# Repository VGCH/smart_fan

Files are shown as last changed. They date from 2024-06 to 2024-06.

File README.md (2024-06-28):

## Проект домашней автоматизации вытяжной вентиляции 

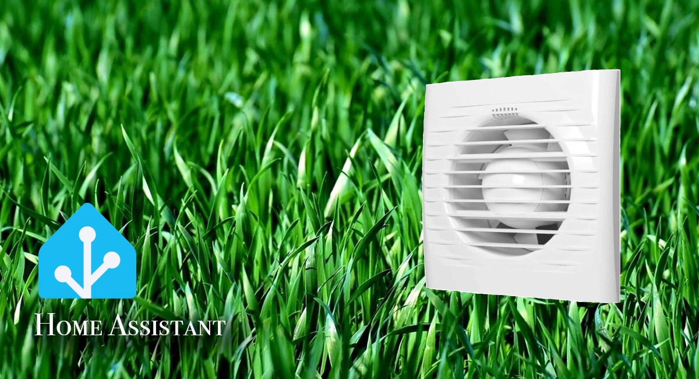
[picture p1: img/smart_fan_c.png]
Иллюстрация к проекту


Принципиальная схема системы управления
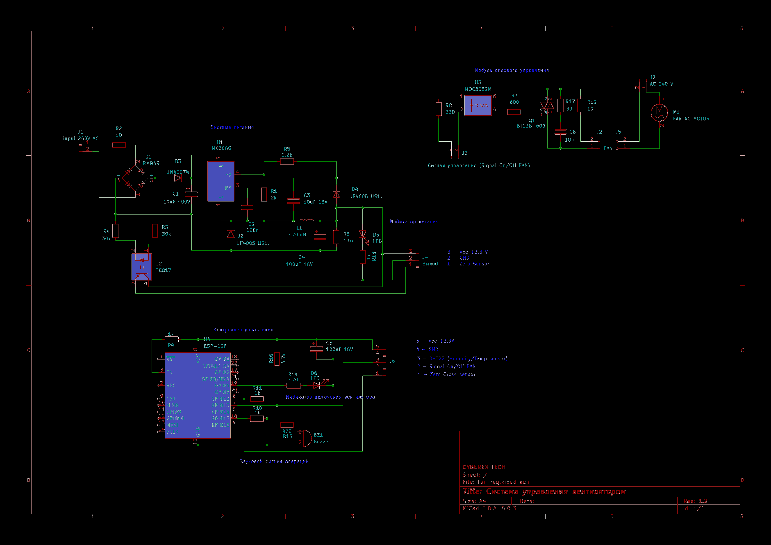
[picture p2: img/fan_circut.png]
Принципиальная схема


Полное описание в статье на Хабр

[Ссылка на статью ](https://habr.com/ru/articles/823752/)

Поддержать автора можно на Boosty

[Ссылка на Boosty](https://boosty.to/cyberex_tech)

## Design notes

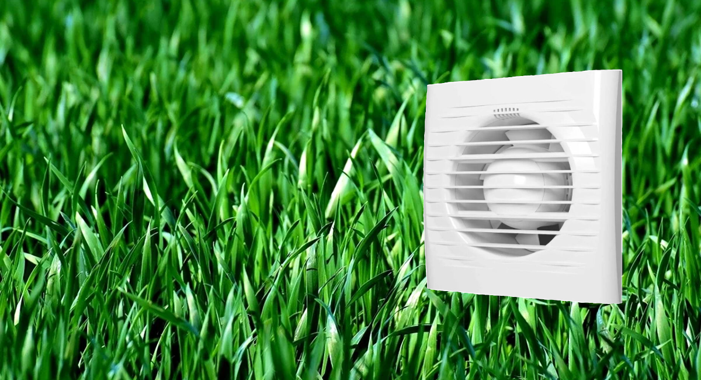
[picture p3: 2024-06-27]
img/smart_fan.png

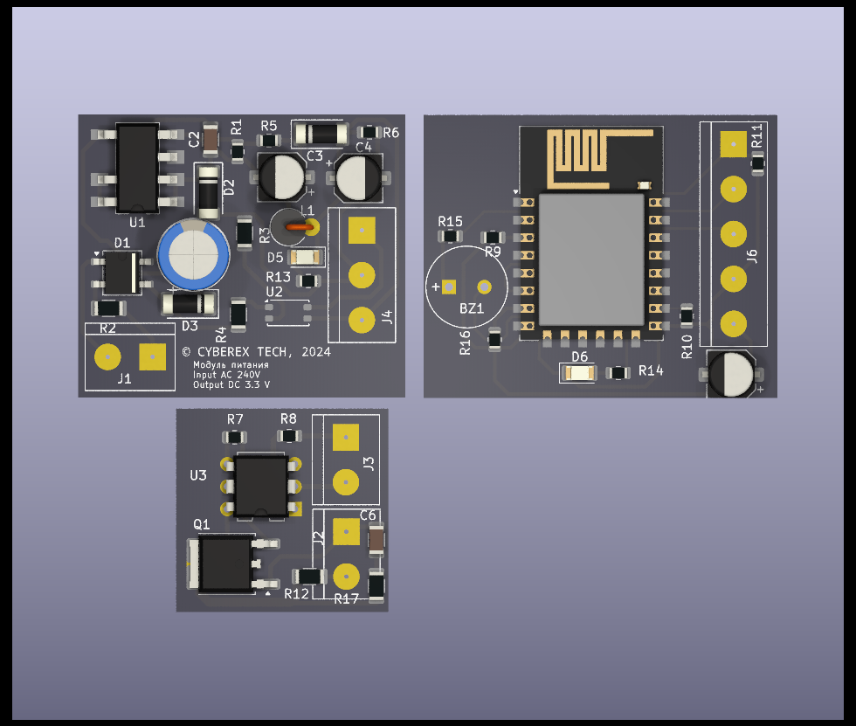
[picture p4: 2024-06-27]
fan_reg/fan_reg.png

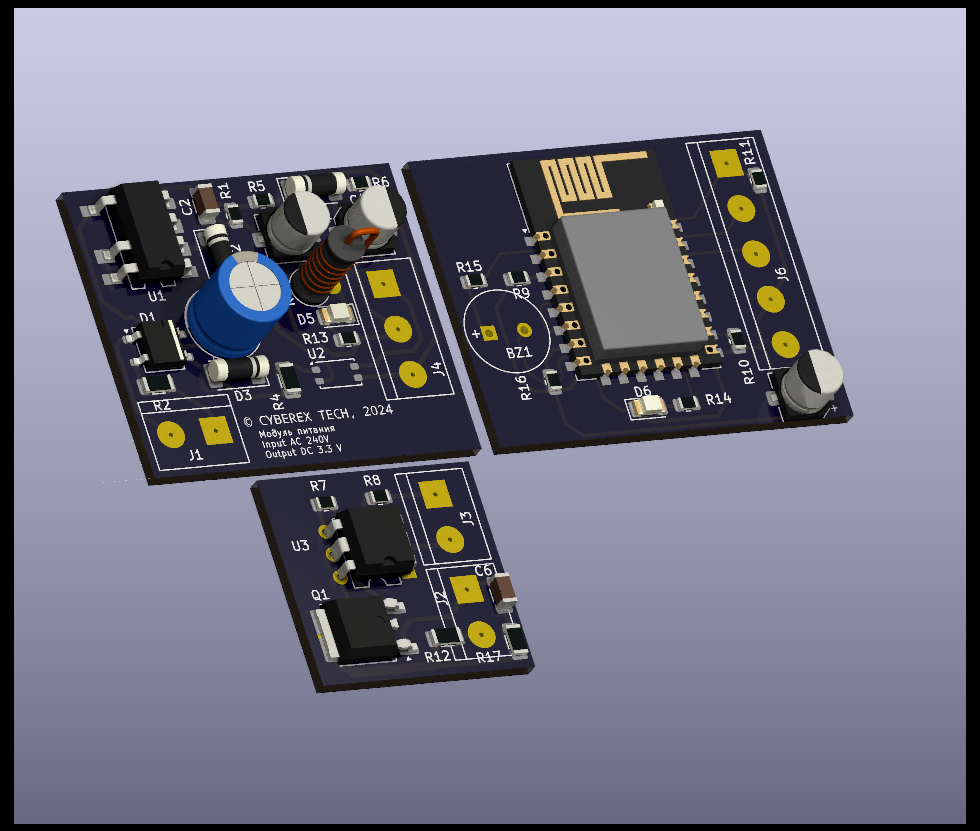
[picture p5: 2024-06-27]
fan_reg/fan_reg2.png

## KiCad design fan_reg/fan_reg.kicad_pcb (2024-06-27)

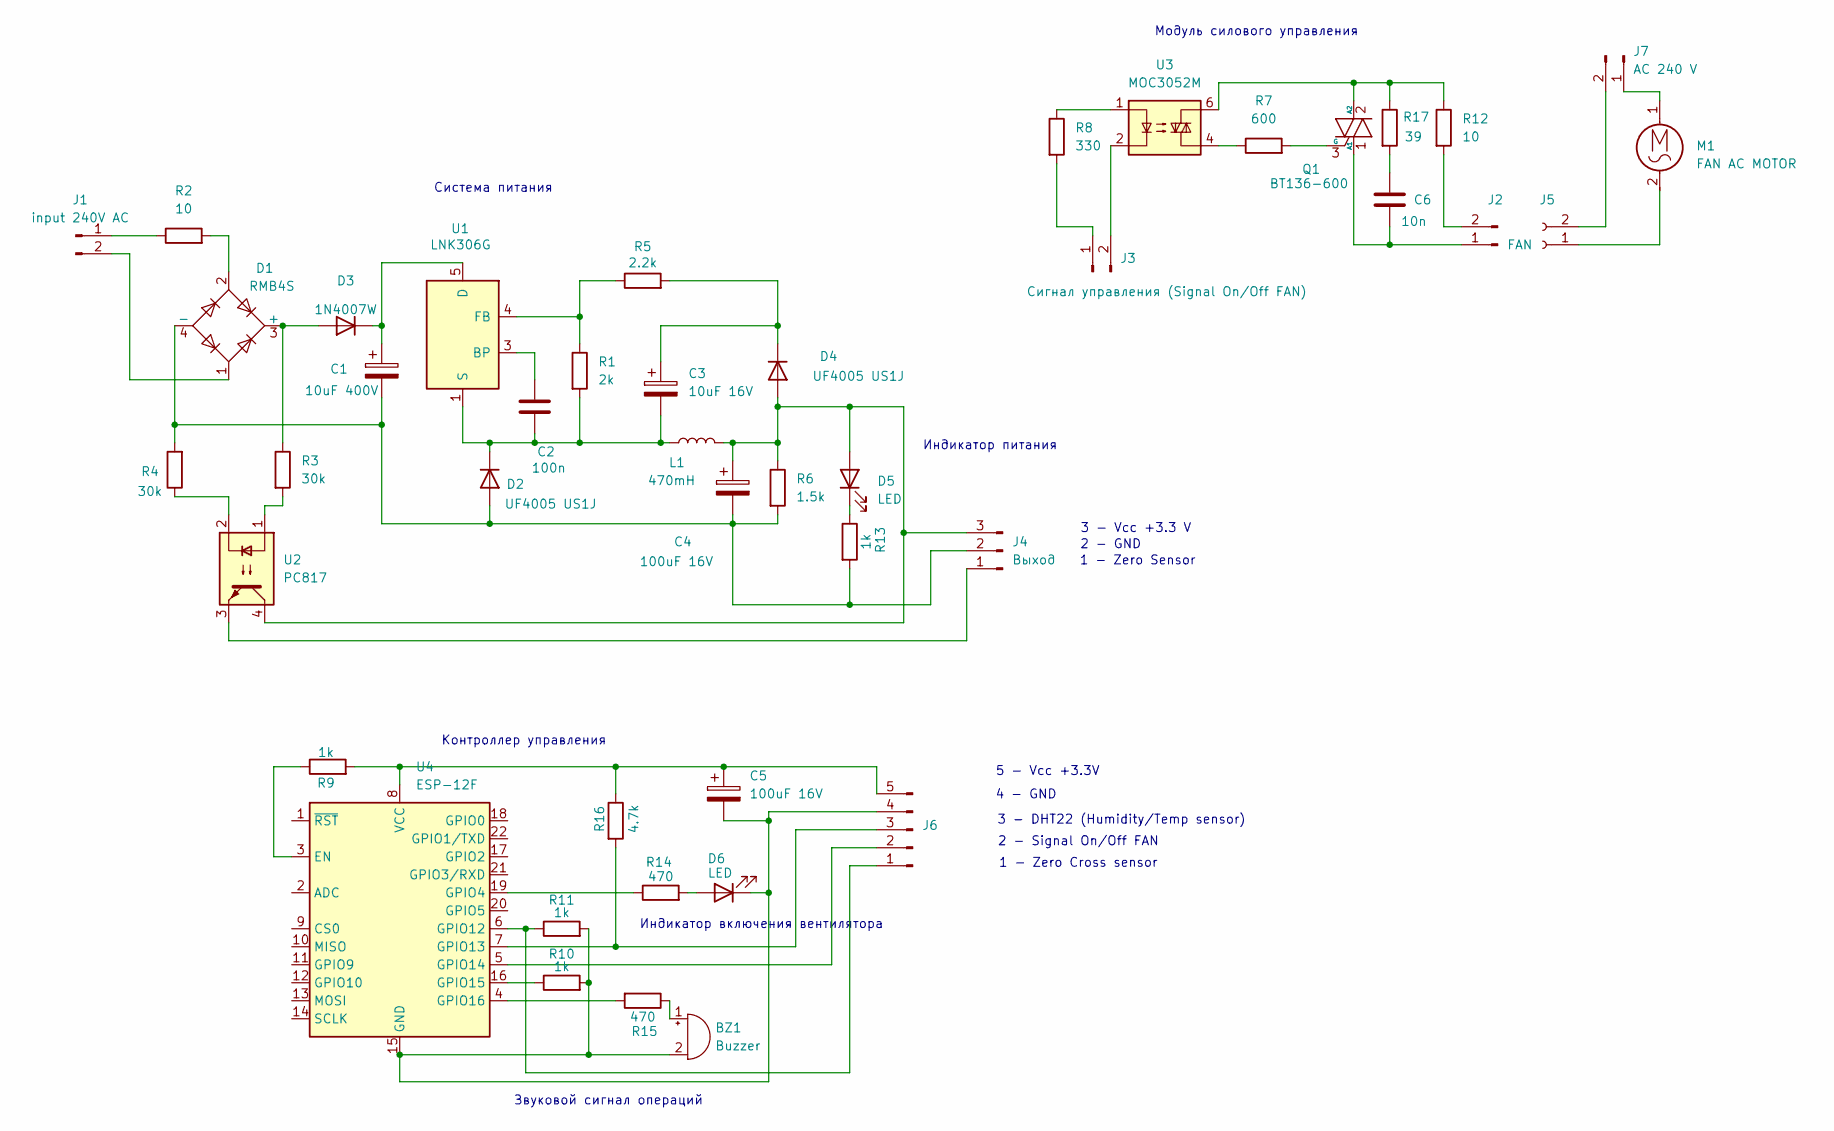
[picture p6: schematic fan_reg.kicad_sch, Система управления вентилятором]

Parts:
BZ1: Buzzer; MagneticBuzzer_PUI_AT-0927-TT-6-R
C1: 10uF 400V; CP_Radial_D8.0mm_P3.80mm
C2: 100n; C_1206_3216Metric
C3: 10uF 16V; CP_Elec_5x5.4
C4, C5: 100uF 16V; CP_Elec_5x5.4
C6: 10n; C_1206_3216Metric
D1: RMB4S; TO-269AA
D2, D4: UF4005 US1J; D_MELF
D3: 1N4007W; D_MELF
D5, D6: LED; LED_1206_3216Metric
J1: input 240V AC; TerminalBlock_bornier-2_P5.08mm
J2: FAN; TerminalBlock_bornier-2_P5.08mm
J3: Сигнал управления (Signal On/Off FAN); TerminalBlock_bornier-2_P5.08mm
J4: Выход; TerminalBlock_bornier-3_P5.08mm
J5: (no value)
J6: TerminalBlock_bornier-5_P5.08mm
J7: AC 240 V
L1: 470mH; L_Axial_L9.5mm_D4.0mm_P2.54mm_Vertical_Fastron_SMCC
M1: FAN AC MOTOR
Q1: BT136-600; TO-252-2
R1: 2k; R_0805_2012Metric
R2, R12: 10; R_1206_3216Metric
R3, R4: 30k; R_1206_3216Metric
R5: 2.2k; R_0805_2012Metric
R6: 1.5k; R_0805_2012Metric
R7: 600; R_0805_2012Metric
R8: 330; R_0805_2012Metric
R9, R10, R11, R13: 1k; R_0805_2012Metric
R14, R15: 470; R_0805_2012Metric
R16: 4.7k; R_0805_2012Metric
R17: 39; R_1206_3216Metric
U1: LNK306G; PowerIntegrations_SMD-8B
U2: PC817; Panasonic_APV-AQY_SSOP-4_4.45x2.65mm_P1.27mm
U3: MOC3052M; DIP-6_W7.62mm
U4: ESP-12F; ESP-12E

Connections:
unnamed: BZ1.1 (+), R15.1
unnamed: BZ1.2 (-), C5.2, D6.1 (K), J6.4, R10.2, R11.2, U4.15 (GND)
unnamed: C6.1, R17.2
unnamed: D1.3 (+), D3.2 (A), R3.1
unnamed: C1.2, C4.2, D1.4 (-), D2.2 (A), J4.2, R4.2, R6.2, R13.2
unnamed: D1.2, R2.2
unnamed: C2.1, C3.2, D2.1 (K), L1.1, R1.2, U1.1 (S), U1.2 (S), U1.7 (S), U1.8 (S)
unnamed: C1.1, D3.1 (K), U1.5 (D)
unnamed: C4.1, D4.2 (A), D5.2 (A), J4.3, L1.2, R6.1, U2.4
unnamed: C3.1, D4.1 (K), R5.2
unnamed: D5.1 (K), R13.1
unnamed: D6.2 (A), R14.2
unnamed: J1.1, R2.1
unnamed: D1.1, J1.2
unnamed: C6.2, J2.1, Q1.1 (A1)
unnamed: J2.2, R12.2
unnamed: J3.1, R8.2
unnamed: J3.2, U3.2
unnamed: J4.1, U2.3
unnamed: J5.1, M1.2
unnamed: J5.2, J7.2
unnamed: J6.1, R11.1, U4.6 (GPIO12)
unnamed: J6.2, U4.5 (GPIO14)
unnamed: J6.3, R16.2, U4.7 (GPIO13)
unnamed: C5.1, J6.5, R9.2, R16.1, U4.8 (VCC)
unnamed: J7.1, M1.1
unnamed: Q1.2 (A2), R12.1, R17.1, U3.6
unnamed: Q1.3 (G), R7.2
unnamed: R3.2, U2.1
unnamed: R4.1, U2.2
unnamed: R7.1, U3.4
unnamed: R8.1, U3.1
unnamed: C2.2, U1.3 (BP)
unnamed: R1.1, R5.1, U1.4 (FB)
unnamed: R9.1, U4.3 (EN)
unnamed: R14.1, U4.19 (GPIO4)
unnamed: R10.1, U4.16 (GPIO15)
unnamed: R15.2, U4.4 (GPIO16)

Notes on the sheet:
4 - GND
Индикатор включения вентилятора
Модуль силового управления
3 - DHT22 (Humidity/Temp sensor)
Контроллер управления
2 - GND
5 - Vcc +3.3V
1 - Zero Cross sensor
3 - Vcc +3.3 V
1 - Zero Sensor
2 - Signal On/Off FAN
Звуковой сигнал операций
Система питания
Индикатор питания

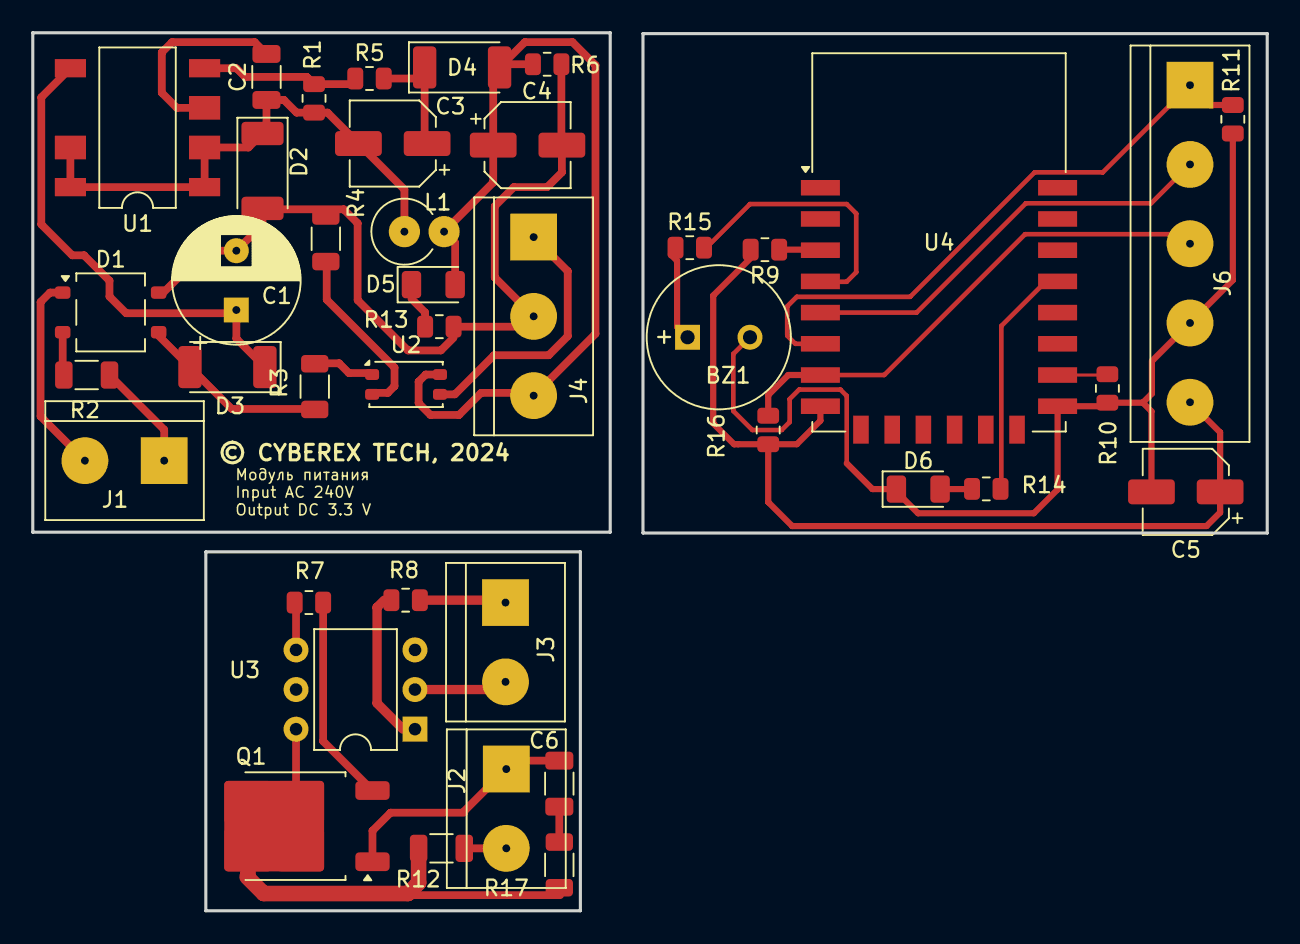
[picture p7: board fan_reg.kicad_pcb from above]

Board: 2 copper layers, 79.1 x 56.3 mm, 41 parts (0 on the bottom side), 35 nets.

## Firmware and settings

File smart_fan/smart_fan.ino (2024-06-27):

/* Устройство для управления вытяжным вентилятором
 *  © CYBEREX Tech, 2024
 * 
 */

#include <ESP8266WiFi.h>
#include <WiFiClient.h>
#include <ESP8266WebServer.h>
#include <ESP8266HTTPUpdateServer.h>
#include <DNSServer.h>
#include <ESP8266mDNS.h>
#include <EEPROM.h>
#include <ESP8266SSDP.h>
#include <PubSubClient.h>
#include "DHTesp.h"
#include <AM2302-Sensor.h>
#include <Wire.h>
#include "const_js.h"



#define on_off_fan    14                    // Пин управления питанием
#define DHT22_pin     13                    // Пин датчика температуры и влажности
#define DHT22_vin     5                     // Пин подачи питания на датчик
#define zero_sensor   12                    // Датчик нуля 
#define on_off_ind    4                     // Индикатор включения вентилятора
#define buzer         16                    // Пищалка
DHTesp dht;

// WEBs
ESP8266WebServer server(80);
WiFiClient espClient;
PubSubClient client(espClient);
IPAddress apIP(10, 10, 20, 1);
IPAddress netMsk(255, 255, 255, 0);
ESP8266HTTPUpdateServer httpUpdater;

// DNS server
const byte             DNS_PORT = 53;
DNSServer              dnsServer;

// Текущий статус WLAN
unsigned int status = WL_IDLE_STATUS;

// Переменные для хранения статуса сетевого подключения
boolean connect;
boolean wi_fi_st;

boolean stat_reboot, led_stat, stat_wifi, fan_on, stat; 

// Переменные используемые для CaptivePortal
const char *myHostname  = "Cyberex_SmartFAN";            // Имя создаваемого хоста Cyberex_SmartFAN.local 
const char *softAP_ssid = "CYBEREX-SmartFAN";            // Имя создаваемой точки доступа Wi-Fi

String version_code = "CF-1.20.06.24";

float hum = 0.0;
float temp = 0.0;
float auto_on_hum;
//timers
uint32_t low_t, med_t, prevMills, lastMsg, impOnDelay, reboot_t, lastConnectTry, auto_check_time;
float frequency = 0;
//int fq_count;

int count_rf = 0;
//int level;

// Структура для хранения токенов сессий 
struct Token {
    String value;
    long created;
    long lifetime;
};

Token   tokens[20];                    // Длина массива структур хранения токенов 

#define TOKEN_LIFETIME 6000000         // время жизни токена в секундах

#define MAX_STRING_LENGTH 30           // Максимальное количество символов для хранения в конфигурации


// Структура для хранения конфигурации устройства
struct {
     boolean mqtt_en;
     int     mqtt_time;
     int     statteeprom; 
     int     counter_coeff;
     float   total;
     char    mySSID[MAX_STRING_LENGTH];
     char    myPW[MAX_STRING_LENGTH];
     char    mqtt_serv[MAX_STRING_LENGTH];
     String  mqtt_user;
     String  mqtt_passw;
     String  mqtt_id;
     String  mqtt_topic;
     String  passwd; 
     float   auto_off; 
     float   auto_on; 
     boolean auto_en;  
  } settings;

  int fan_level = 0;
  int set_delay = 5000;

void setup() {
    EEPROM.begin(sizeof(settings));                                 // Инициализация EEPROM в соответствии с размером структуры конфигурации      
    pinMode(on_off_fan, OUTPUT);
    pinMode(on_off_ind, OUTPUT);
    pinMode(buzer,      OUTPUT);
    pinMode(DHT22_vin,  OUTPUT);
    digitalWrite(DHT22_vin, HIGH);
    beep_buz(millis(), true);
    dht.setup(DHT22_pin, DHTesp::DHT22);
    read_config();                                                  // Чтение конфигурации из EEPROM
    check_clean();                                                  // Провека на запуск устройства после первичной прошивки
     if(String(settings.passwd) == ""){   
        settings.passwd = "admin";                                  // Если  переменная settings.passwd пуста, то назначаем пароль по умолчанию
     }
     //if(settings.counter_coeff > 0 && settings.counter_coeff <= 100 ){
     //     fan_level = settings.counter_coeff;
     // }else{
     //     fan_level = 0;
    //  }
     //level = map (fan_level, 0, 100, 1, set_delay);
     
     
     WiFi.mode(WIFI_STA);                                           // Выбираем режим клиента для сетевого подключения по Wi-Fi                
     WiFi.hostname("Smart FAN [CYBEREX TECH]");                    // Указываеем имя хоста, который будет отображаться в Wi-Fi роутере, при подключении устройства
     if(WiFi.status() != WL_CONNECTED) {                            // Инициализируем подключение, если устройство ещё не подключено к сети
           WiFi.begin(settings.mySSID, settings.myPW);
      }

     for(int x = 0; x < 160; x ++){                                  // Цикл ожидания подключения к сети (80 сек)
          if (WiFi.status() == WL_CONNECTED){ 
                stat_wifi = true;
                break;
           }
               delay(500); 
      
          }

     if(WiFi.status() != WL_CONNECTED) {                             // Если подключение не удалось, то запускаем режим точки доступа Wi-Fi для конфигурации устройства
            WiFi.mode(WIFI_AP_STA);
            WiFi.softAPConfig(apIP, apIP, netMsk);
            WiFi.softAP(softAP_ssid);
            stat_wifi = false;
        }
        
        delay(2000);
        // Запускаем DNS сервер
        dnsServer.setErrorReplyCode(DNSReplyCode::NoError);
        dnsServer.start(DNS_PORT, "*", apIP);
        // WEB страницы
        server.on("/", page_process);
        server.on("/login", handleLogin);
        server.on("/script.js", reboot_devsend);
        server.on("/style.css", css);
        server.on("/index.html", HTTP_GET, [](){
        server.send(200, "text/plain", "IoT Radiation Sensor"); });
        server.on("/description.xml", HTTP_GET, [](){SSDP.schema(server.client());});
        server.on("/inline", []() {
        server.send(200, "text/plain", "this works without need of authentification");
        });
        server.onNotFound(handleNotFound);
        // Здесь список заголовков для записи
        const char * headerkeys[] = {"User-Agent", "Cookie"} ;
        size_t headerkeyssize = sizeof(headerkeys) / sizeof(char*);
        // Запускаем на сервере отслеживание заголовков 
        server.collectHeaders(headerkeys, headerkeyssize);
        server.begin();
        connect = strlen(settings.mySSID) > 0;                                            // Статус подключения к Wi-Fi сети, если есть имя сети
        SSDP_init();
        attachInterrupt(digitalPinToInterrupt(zero_sensor), FQ_counter, FALLING);        // Задействуем аппаратное прерывание для измерения импульсов нулевого датчика
              
}

void loop() {
        portals();
        dnsServer.processNextRequest();
        server.handleClient();  
        reboot_dev_delay();
        get_DHT22_data();
        MQTT_send(); 
        auto_process();
}

void reboot_devsend(){
   server.send(200, "text", reb_d);
}

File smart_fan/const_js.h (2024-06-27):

const char reb_d[] = R"rawliteral(
   function rebootdev() {
        modal.style.display = "block";
     }
   var t = 60;
   var time = document.getElementsByClassName("clock")[0];
     function fun() {
         t--;
        time.innerHTML = "<b>Оставшееся время: "+ t +" сек.</b>"
       if(t <= 0) {
         location.href = "/";
         clearInterval(inter);
       }
   }
   
  function rebootdev_s() {
      var msg = document.getElementsByClassName("modal-body")[0];
      var req5 = new XMLHttpRequest();
            req5.open('GET','/?page=dev_reboot');
            req5.onreadystatechange = function(){
              if (req5.readyState === 4 && req5.status === 200) {
                     msg.innerHTML ="<br><b>Выполняется перезапуск устройства...</b><br>"
                     var inter = setInterval("fun()", 1000);
              }
            }
        req5.send();
})rawliteral";

//=========================================

const char html[] = R"(
                  body {
                  background: linear-gradient(to bottom, #060345, #023f78, #540110, #013a42, #1f3d6e);
                    }
                  form, div.frame {
                       margin: 20px auto 0;
                       max-width: 500px;
                       padding: 10px;
                       border-radius: 10px;
                       background-color: #fff;
                    }
                  div#response2, div#response21 {
                       margin: 10px auto 0;
                       max-width: 500px;
                       padding: 20px;
                       border-radius: 10px;
                       background: linear-gradient(to bottom right, #9df3f5, #e6e8e7);
                    }
                    label {
                        display: block;
                        color: #5769a1;
                        margin: 10px;
                    }
                  input[type=text], input[type=password], input[type=number], input[type=file], select {
                        width: 100%;
                        padding: 10px;
                        margin-bottom: 15px;
                        border: 1px solid #ccc;
                        border-radius: 4px;
                        box-sizing: border-box;
                      }
                     input[type=submit] {
                        background-color: #3482f7;
                        color: white;
                        padding: 12px 20px;
                        border: none;
                        border-radius: 4px;
                        cursor: pointer;
                     }
                    h2 {
                        text-align: center;
                        margin-top: 10px;
                        font-size: 30px;
                        color: white;
                    }
                    text {
                       text-align: left;
                       margin-top: 5px;
                       font-size: 18px;
                       font-family: Noto Sans;
                       color: #023c52;
                     }
                    div.live {
                       text-align: right;
                       margin-top: 0px;
                       font-size: 30px;
                       font-family: Arial;
                       color: #066094;
                     }
                     div.livePM {
                       text-align: right;
                       margin-top: 0px;
                       font-size: 35px;
                       font-family: Monotype Corsiva;
                       color: #800404;
                     }
                    div.modal {
                       text-align: left;
                       margin-top: 0px;
                       font-size: 30px;
                       color: #066094;
                     }
                      a {
                       text-align: center;
                       margin-top: 0px;
                       font-size: 16px;
                       text-decoration: none;
                       color: #9ee8e8;
                     }
                     a.mod {
                       text-align: center;
                       margin-top: 0px;
                       font-size: 18px;
                       text-decoration: none;
                       color: #3e5d80;
                     }
                    .spoiler input, .spoiler div  { 
                        display: none; 
                     }
                    .spoiler :checked ~ div {
                     display: block;
                     }
                     footer {
                       text-align: center;
                       margin-top: 10px;
                       font-size: 15px;
                       color: #cbd6f2;
                     }
                      #myBtn {                     
                      background-color: #9C27B0;  
                      color: white; 
                      padding: 12px 16px;
                      font-size: 18px;
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
